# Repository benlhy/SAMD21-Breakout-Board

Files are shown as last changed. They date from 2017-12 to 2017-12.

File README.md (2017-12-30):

# SAMD21-Breakout-Board
A breakout board for the SAMD21, better known as the M0+. All pins are broken out with the additon of USB and LiPo charging hardware

This breakout board combines both the Adafruit M0 Feather and the Sparkfun board. From the Adafruit board comes Lipo charging, and from the Sparkfun board comes the full breakout. The header pins for SWO programming are broken out, and a microUSB interface is provided just in case you do compile your own bootloader.

# Firmware references
1. https://learn.adafruit.com/compiling-m0-atsamd21-bootloader/compile
2. https://github.com/adafruit/Adafruit-Feather-M0-Basic-Proto-PCB
3. https://github.com/sparkfun/SAMD21_Dev_Breakout
4. https://github.com/sparkfun/SAMD21_Mini_Breakout

# Thanks
Adafruit and Sparkfun invests time and resources in providing open designs. This project would not have been possible without their guides. Support Adafruit and Sparkfun and open-source hardware by purchasing products from them!

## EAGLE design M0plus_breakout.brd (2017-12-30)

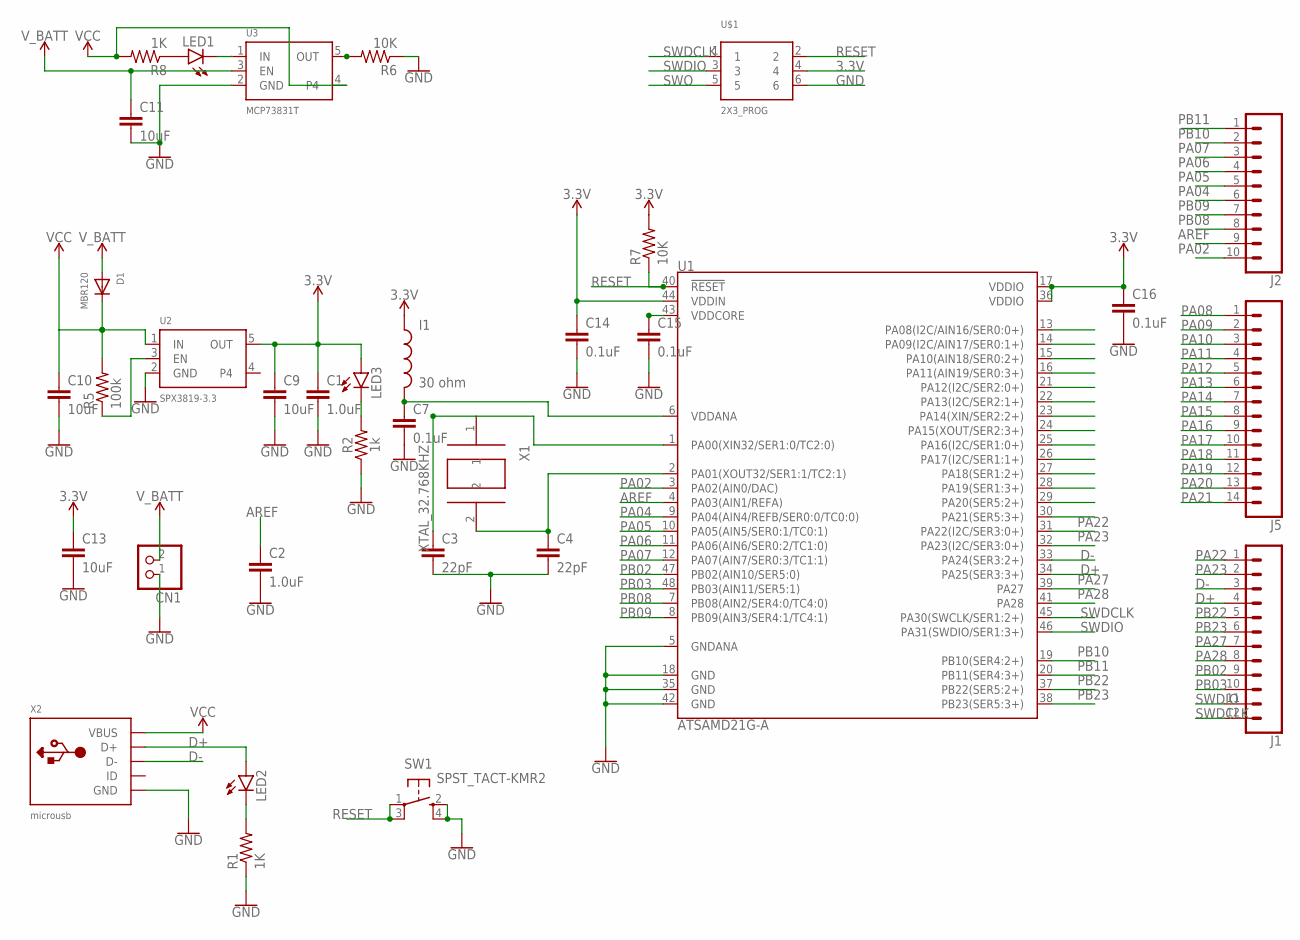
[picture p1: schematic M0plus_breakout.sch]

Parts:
C1, C2: 1.0uF; 0603-CAP
C3, C4: 22pF; 0603-CAP
C7: 0.1uF; 0805
C9, C10, C11, C13: 10uF; 0805
C14, C15, C16: 0.1uF; 0603-CAP
CN1: JST_2PIN; JSTPH2
D1: MBR120; SOD-123
I1: 30 ohm; 0805
J1: CONN_12; 1X12
J2: CONN_10"; 1X10
J5: CONN_14; 1X14
LED1, LED2, LED3: LED0603; LED-0603
R1, R8: 1K; 0603-RES
R2: 1k; 0603
R5: 100k; 0603-RES
R6, R7: 10K; 0603-RES
SW1: SPST_TACT-KMR2; KMR2
U1: ATSAMD21G-A; TQFP-48
U2: SPX3819-3.3; SOT23-5
U3: MCP73831T; SOT23-5
U$1: 2X3_PROG; 2X3-SMD_PROG
X1: XTAL_32.768KHZ; ABS07-32.768KHZ-9-T
X2: microusb; 4UCONN_20329_V2

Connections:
3.3V: C1.1, C9.1, C13.1, C14.1, C16.1, I1.1, LED3.A, R7.2, U1.17 (VDDIO), U1.36 (VDDIO), U1.44 (VDDIN), U2.5 (OUT), U$1.4
AREF: C2.1, J2.9, U1.4 (PA03(AIN1/REFA))
D+: J1.4, LED2.A, U1.34 (PA25(SER3:3+)), X2.D+
D-: J1.3, U1.33 (PA24(SER3:2+)), X2.D-
GND: C1.2, C2.2, C3.2, C4.2, C7.2, C9.2, C10.2, C11.2, C13.2, C14.2, C15.2, C16.2, CN1.1, R1.1, R2.1, R6.1, SW1.2 (S), SW1.4 (S1), U1.5 (GNDANA), U1.18 (GND), U1.35 (GND), U1.42 (GND), U2.2 (GND), U3.2 (GND), U$1.6, X2.BASE@1 (GND), X2.BASE@2 (GND), X2.GND, X2.SPRT@1 (GND), X2.SPRT@2 (GND), X2.SPRT@3 (GND), X2.SPRT@4 (GND)
unnamed: LED1.A, R8.1
unnamed: C3.1, U1.1 (PA00(XIN32/SER1:0/TC2:0)), X1.1
unnamed: C4.1, U1.2 (PA01(XOUT32/SER1:1/TC2:1)), X1.2
unnamed: C15.1, U1.43 (VDDCORE)
unnamed: LED2.C, R1.2
unnamed: C7.1, I1.2, U1.6 (VDDANA)
unnamed: LED3.C, R2.2
unnamed: R5.1, U2.3 (EN)
unnamed: LED1.C, U3.1 (IN)
unnamed: R6.2, U3.5 (OUT)
PA02: J2.10, U1.3 (PA02(AIN0/DAC))
PA04: J2.6, U1.9 (PA04(AIN4/REFB/SER0:0/TC0:0))
PA05: J2.5, U1.10 (PA05(AIN5/SER0:1/TC0:1))
PA06: J2.4, U1.11 (PA06(AIN6/SER0:2/TC1:0))
PA07: J2.3, U1.12 (PA07(AIN7/SER0:3/TC1:1))
PA08: J5.1, U1.13 (PA08(I2C/AIN16/SER0:0+))
PA09: J5.2, U1.14 (PA09(I2C/AIN17/SER0:1+))
PA10: J5.3, U1.15 (PA10(AIN18/SER0:2+))
PA11: J5.4, U1.16 (PA11(AIN19/SER0:3+))
PA12: J5.5, U1.21 (PA12(I2C/SER2:0+))
PA13: J5.6, U1.22 (PA13(I2C/SER2:1+))
PA14: J5.7, U1.23 (PA14(XIN/SER2:2+))
PA15: J5.8, U1.24 (PA15(XOUT/SER2:3+))
PA16: J5.9, U1.25 (PA16(I2C/SER1:0+))
PA17: J5.10, U1.26 (PA17(I2C/SER1:1+))
PA18: J5.11, U1.27 (PA18(SER1:2+))
PA19: J5.12, U1.28 (PA19(SER1:3+))
PA20: J5.13, U1.29 (PA20(SER5:2+))
PA21: J5.14, U1.30 (PA21(SER5:3+))
PA22: J1.1, U1.31 (PA22(I2C/SER3:0+))
PA23: J1.2, U1.32 (PA23(I2C/SER3:0+))
PA27: J1.7, U1.39 (PA27)
PA28: J1.8, U1.41 (PA28)
PB02: J1.9, U1.47 (PB02(AIN10/SER5:0))
PB03: J1.10, U1.48 (PB03(AIN11/SER5:1))
PB08: J2.8, U1.7 (PB08(AIN2/SER4:0/TC4:0))
PB09: J2.7, U1.8 (PB09(AIN3/SER4:1/TC4:1))
PB10: J2.2, U1.19 (PB10(SER4:2+))
PB11: J2.1, U1.20 (PB11(SER4:3+))
PB22: J1.5, U1.37 (PB22(SER5:2+))
PB23: J1.6, U1.38 (PB23(SER5:3+))
RESET: R7.1, SW1.1, SW1.3 (P1), U1.40 (!RESET!), U$1.2
SWDCLK: J1.12, U1.45 (PA30(SWCLK/SER1:2+)), U$1.1
SWDIO: J1.11, U1.46 (PA31(SWDIO/SER1:3+)), U$1.3
SWO: U$1.5
VCC: C10.1, D1.C, R5.2, R8.2, U2.1 (IN), U3.4, X2.VBUS
V_BATT: C11.1, CN1.2, D1.A, U3.3 (EN)

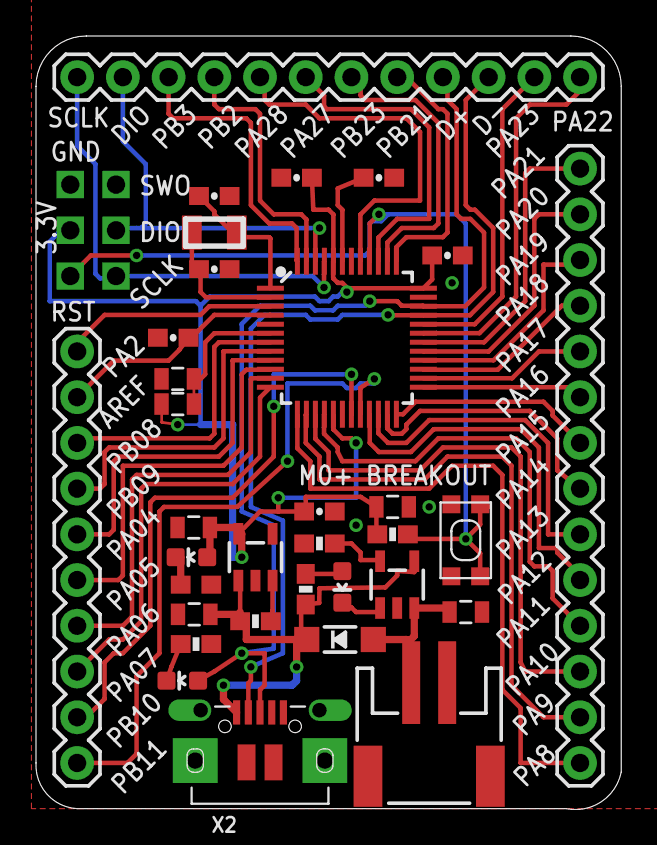
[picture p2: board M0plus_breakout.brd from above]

Board: 2 copper layers, 32.5 x 43.0 mm, 34 parts (0 on the bottom side), 51 nets.

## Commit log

2017-12-30 added schematic
    [M0plus_breakout.brd, M0plus_breakout.sch]
2017-12-30 added power LED
    [M0plus_breakout.brd, M0plus_breakout.sch]

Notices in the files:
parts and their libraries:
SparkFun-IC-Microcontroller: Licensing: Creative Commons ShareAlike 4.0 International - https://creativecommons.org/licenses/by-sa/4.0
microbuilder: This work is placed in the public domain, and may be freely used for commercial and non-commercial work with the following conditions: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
